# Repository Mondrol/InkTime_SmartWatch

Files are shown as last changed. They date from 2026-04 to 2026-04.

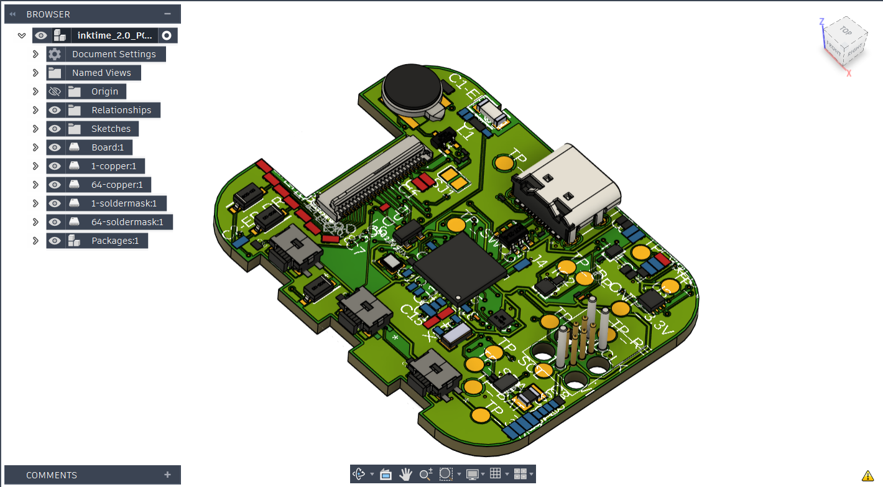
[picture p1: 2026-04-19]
Images/Screenshot 2026-04-19 184838.png

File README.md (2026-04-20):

# INK TIME SMARTWATCH

Un smartwatch bazat pe arhitectura **nRF52840**, echipat cu un ecran **e-Paper** pentru consum ultra-redus de energie și un sistem de alertă haptică.

---

## Cuprins

1. [Diagrama Bloc](#diagrama-bloc)
2. [Descrierea Funcționalității Hardware](#descrierea-funcționalității-hardware)
3. [Bill of Materials (BOM)](#bill-of-materials-bom)
4. [Configurația Pinilor nRF52840](#configurația-pinilor-nrf52840)

---

## Diagrama Bloc

```
┌─────────────────────────────────────────────────────────────┐
│                        POWER SUPPLY                         │
│                                                             │
│  Li-Po Battery (3.7V)                                       │
│       │                                                     │
│       ▼                                                     │
│  BQ25180 (Charger IC)  ◄──── USB Type-C                     │
│       │                                                     │
│       ▼                                                     │
│  RT6160A (Buck-Boost)  ──► 3.3V stable output              │
│       │                                                     │
│  MAX17048 (Fuel Gauge) ──► I2C ──► nRF52840                 │
└─────────────────────────────────────────────────────────────┘

┌─────────────────────────────────────────────────────────────┐
│                     PROCESSING UNIT                         │
│                                                             │
│              nRF52840 (ARM Cortex-M4F)                      │
│         ┌──────────────┴──────────────┐                     │
│         │                            │                      │
│       SPI bus                     I2C bus                   │
│         │                            │                      │
│   e-Paper Display              ┌─────┴──────┐               │
│   (1.54")                      │            │               │
│                            BMA423      DRV2605L              │
│                          (Accel.)    (Haptic Driver)         │
└─────────────────────────────────────────────────────────────┘
```

---

## Descrierea Funcționalității Hardware

Sistemul este construit în jurul SoC-ului **nRF52840**, optimizat pentru un consum ultra-scăzut de energie și securitate hardware.

### Microcontroller — nRF52840

Procesor ARM Cortex-M4F cu unitate de criptare hardware CryptoCell-310. Gestionează stack-ul **Bluetooth Low Energy (BLE)** și coordonează toate perifericele. Rulează la 64 MHz, dar stă majoritatea timpului în modul **System ON Sleep** (~3 µA).

### Sistemul de Alimentare (Power Tree)

| Componentă | Rol |
|---|---|
| **BQ25180** | IC de încărcare cu Power Path — permite încărcarea bateriei LiPo și alimentarea simultană a sistemului via USB Type-C |
| **MAX17048** | Fuel Gauge — măsoară precis starea de încărcare (SoC) și tensiunea bateriei, comunicând prin I2C |
| **RT6160A** | Regulator Buck-Boost — asigură o tensiune stabilă de 3.3V indiferent de nivelul de descărcare al bateriei |

### Afișaj e-Paper (1.54")

Display de tip *Electronic Ink* care consumă curent **doar la refresh**. Include un circuit de protecție cu un PFET (DMG2305UX) pentru a opri complet alimentarea ecranului în standby, eliminând scurgerile de curent. Comunică cu MCU prin **SPI** (interfață de mare viteză).

### Senzor de Mișcare — BMA423

Accelerometru triaxial de mică putere (12-bit, 3 axe). Utilizat pentru:
- **Pedometru** (numărarea pașilor)
- **Detectarea gesturilor** — ex: *tilt-to-wake* (ridicarea mâinii aprinde ecranul)

### Driver Haptic — DRV2605L

Controlează motorul de vibrații (ERM/LRA) folosind librării de efecte pre-programate pentru feedback tactil. Comunică prin **I2C**.

### Cristale de Referință

**Cristal 32 MHz (X1)** — esențial pentru funcționarea blocului radio (Bluetooth). Oferă referința de înaltă frecvență necesară stabilității semnalului RF și procesării rapide a datelor.

**Cristal 32.768 kHz (X2)** — componentă critică pentru optimizarea consumului. Permite funcționarea ceasului de timp real (RTC) în modurile de **Deep Sleep**, menținând precizia timpului cu un consum infim de energie, fără a fi nevoie de oscilatorul intern RC (mai puțin precis și mai consumator).

### Antena 2.4 GHz

Antenă de tip **SMD ceramic** (Johanson 2450AT18B100E) pentru frecvența de 2.4 GHz (BLE). A fost respectată o zonă de *keep-out* (fără cupru) pe toate straturile sub antenă pentru a preveni atenuarea semnalului.

### Interfețe de Comunicație

| Interfață | Periferice conectate |
|---|---|
| **I2C** | BMA423, DRV2605L, BQ25180, MAX17048 |
| **SPI** | Display e-Paper (interfață de mare viteză) |
| **GPIO cu întreruperi** | Butoane UP / ENTER / DOWN |
| **SWD** | Programare și debugging via Tag-Connect (J2) |

### Consumul de Energie

Bateria de **250 mAh** susține o autonomie estimată de **30–45 zile**, datorită:
- Ecranului e-Paper care nu consumă energie între actualizări
- Senzorilor configurați pe modul de consum minim cu întreruperi
- nRF52840 în System ON Sleep (~3 µA) marea majoritate a timpului

---

## Bill of Materials (BOM)

| Componentă | Descriere | Qty | Ref. Designator | Producător |
|---|---|:---:|---|---|
| **nRF52840** | MCU ARM Cortex-M4F + BLE 5.0 | 1 | U1 | Nordic Semiconductor |
| **BQ25180YBGR** | IC Încărcare Baterie Li-Po/Li-Ion | 1 | IC1 | Texas Instruments |
| **MAX17048G+T10** | Fuel Gauge 1-Cell cu ModelGauge | 1 | U2 | Analog Devices (Maxim) |
| **RT6160AWSC** | Regulator Buck-Boost DC-DC I2C | 1 | IC9 | Richtek |
| **DRV2605YZFR** | Driver Haptic ERM/LRA | 1 | IC2 | Texas Instruments |
| **BMA423** | Accelerometru Triaxial Low-g 12-bit | 1 | IC3 | Bosch Sensortec |
| **2450AT18B100E** | Antenă SMD 2.45 GHz (BLE) | 1 | ANT1 | Johanson Technology |
| **KH-TYPE-C-16P** | Conector USB Type-C 16 pini | 1 | J4 | Kinghelm |
| **503480-2400** | Conector FPC 24 pini, pitch 0.5mm (Display) | 1 | J1 | Molex |
| **TC2030-IDC** | Conector programare Tag-Connect 6 pini | 1 | J2 | Tag-Connect |
| **USBLC6-2SC6Y** | Diodă TVS Protecție ESD (USB) | 1 | D3 | STMicroelectronics |
| **MBR0530** | Diodă Schottky 30V / 0.5A | 3 | D2, D4, D5 | ON Semiconductor |
| **DMG2305UX-7** | MOSFET P-Channel 20V / 4.2A (e-Paper power switch) | 1 | Q1 | Diodes Inc. |
| **SI1308EDL-T1-GE3** | MOSFET N-Channel 30V / 1.5A | 1 | Q3 | Vishay Siliconix |
| **EVP-AKE31A** | Butoane Tactile SMD (Navigare) | 3 | SW_UP, SW_DN, SW_ENT | Panasonic |
| **744043680** | Inductor / Bobină 68 µH | 1 | L5 | Würth Elektronik |
| **FTC252012SR47MBCA** | Inductor SMD 0.47 µH | 1 | L7 | TDK |
| **Cristal 32 MHz** | Referință RF pentru bloc radio BLE | 1 | X1 | — |
| **Cristal 32.768 kHz** | Referință RTC pentru Deep Sleep | 1 | X2 | — |
| **Condensatori / Rezistențe** | Pasive SMD (0201, 0402) | ~60 | C*, R* | — |
| **Test Pads** | Puncte de test (3.3V, GND, SWD, I2C etc.) | 14 | TP_* | — |

---

## Configurația Pinilor nRF52840

### Interfața Ecranului e-Paper (SPI)

| Semnal | Pin nRF52 | Direcție | Descriere |
|---|---|---|---|
| EPD_SCK | P0.28 | Output | Clock SPI pentru refresh ecran |
| EPD_MOSI | P0.29 | Output | Date imagine (frame buffer) |
| EPD_CS | P0.30 | Output | Chip Select — activează comunicația cu display-ul |
| EPD_DC | P0.31 | Output | Data/Command — diferențiază comenzile de datele de imagine |
| EPD_BUSY | P0.04 | Input | Semnal activ cât timp ecranul procesează un refresh |
| EPD_PWR | P0.13 | Output | Enable alimentare ecran — dezactivat complet în standby |

### Magistrala Senzorilor (I2C)

Toți senzorii (BMA423, MAX17048, DRV2605L, BQ25180) împart aceeași magistrală I2C.

| Semnal | Pin nRF52 | Descriere |
|---|---|---|
| I2C_SDA | P0.26 | Linie de date (partajată între toți senzorii) |
| I2C_SCL | P0.27 | Linie de clock |

### Butoane de Navigare

Pini configurați cu pull-up intern și capabili de **wake-up din Deep Sleep** prin întrerupere hardware.

| Buton | Pin nRF52 | Funcție |
|---|---|---|
| UP | P1.00 | Navigare meniu — sus |
| DOWN | P1.01 | Navigare meniu — jos |
| ENTER | P1.02 | Selecție / Confirmare |

### Alte Conexiuni Importante

| Semnal | Pin nRF52 | Descriere |
|---|---|---|
| SHAKER_EN | P0.02 | PWM / Enable pentru driver haptic DRV2605 |
| GAUGE_INT | P1.15 | Întrerupere de la MAX17048 la nivel critic de baterie |
| LED_1 | P0.13 | LED de stare pentru notificări vizuale |
| LED_2 | P0.14 | LED de stare secundar |
| SWDIO | — | Programare și debug via Tag-Connect J2 |
| SWDCLK | — | Clock SWD pentru J-Link |

---

## Imagini PCB

| PCB 3D View | Exploded View | Final View |
|---|---|---|
| `./Images/PCB_3D.png` | `./Images/exploded_view.png` | `./Images/final_view.png` |

---

*INK TIME SMARTWATCH — Hardware Design Documentation*

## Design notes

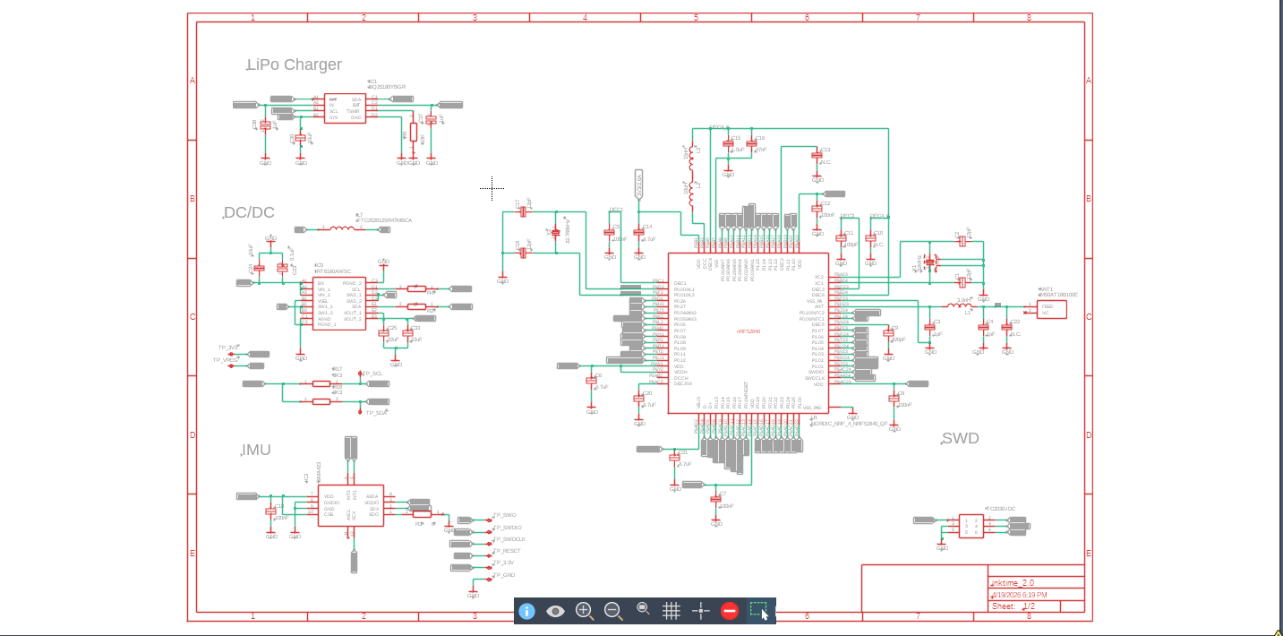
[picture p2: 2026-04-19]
Images/Screenshot 2026-04-19 184958.png

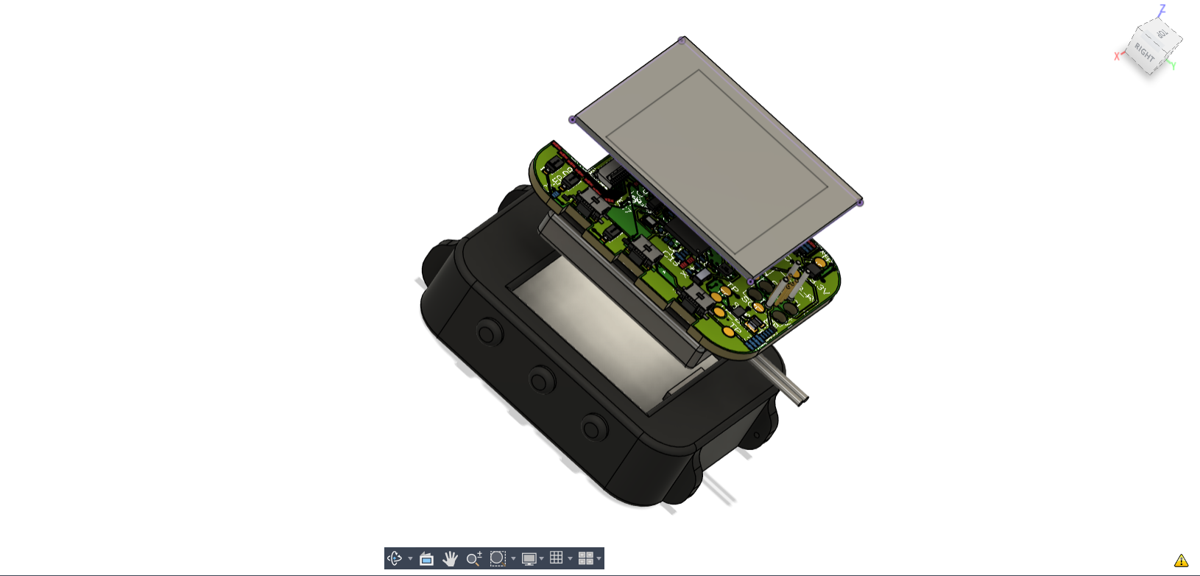
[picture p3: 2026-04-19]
Images/Screenshot 2026-04-19 185646.png

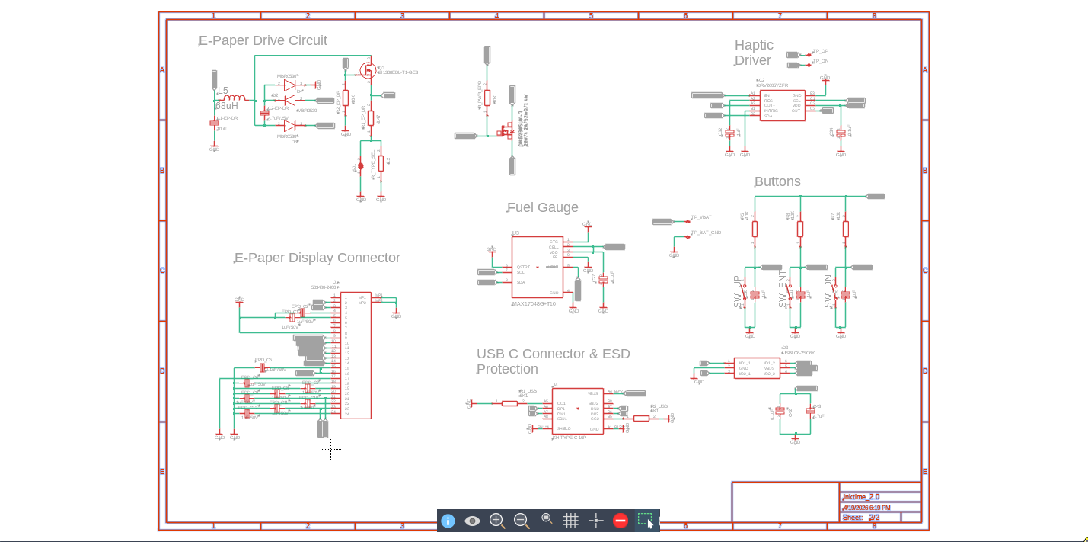
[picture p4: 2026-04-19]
Images/Screenshot 2026-04-19 184948.png

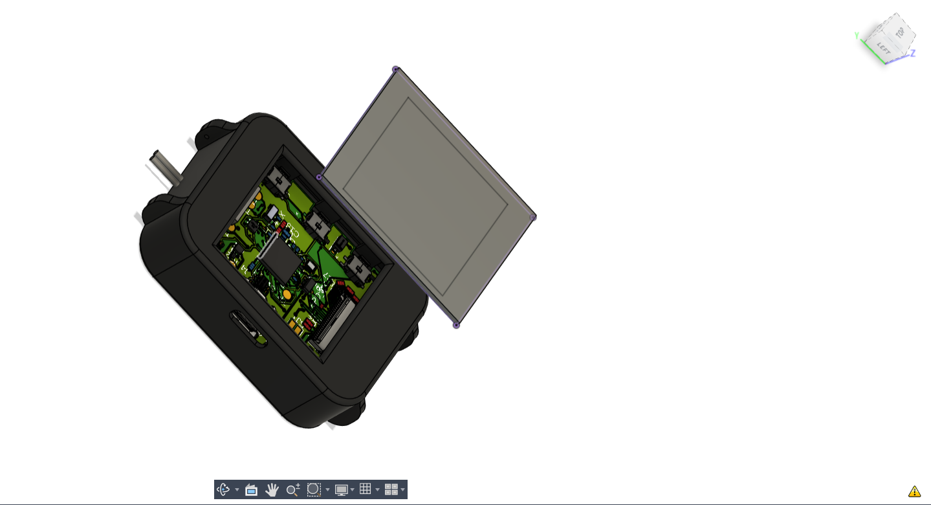
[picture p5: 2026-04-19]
Images/Screenshot 2026-04-19 185936.png

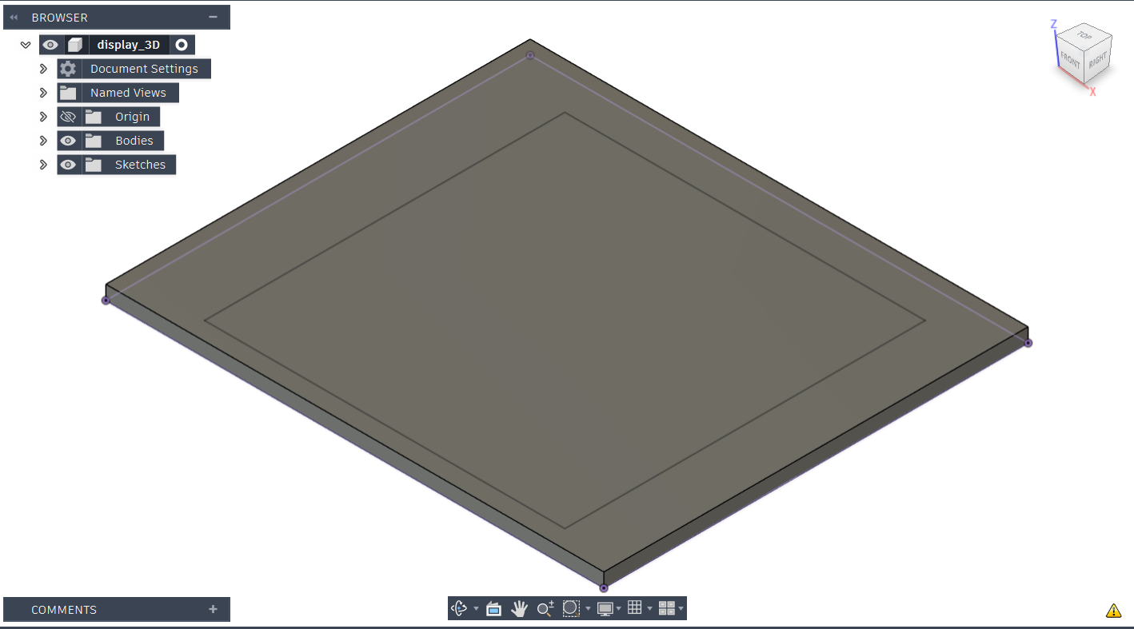
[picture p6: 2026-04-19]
Images/Screenshot 2026-04-19 184855.png

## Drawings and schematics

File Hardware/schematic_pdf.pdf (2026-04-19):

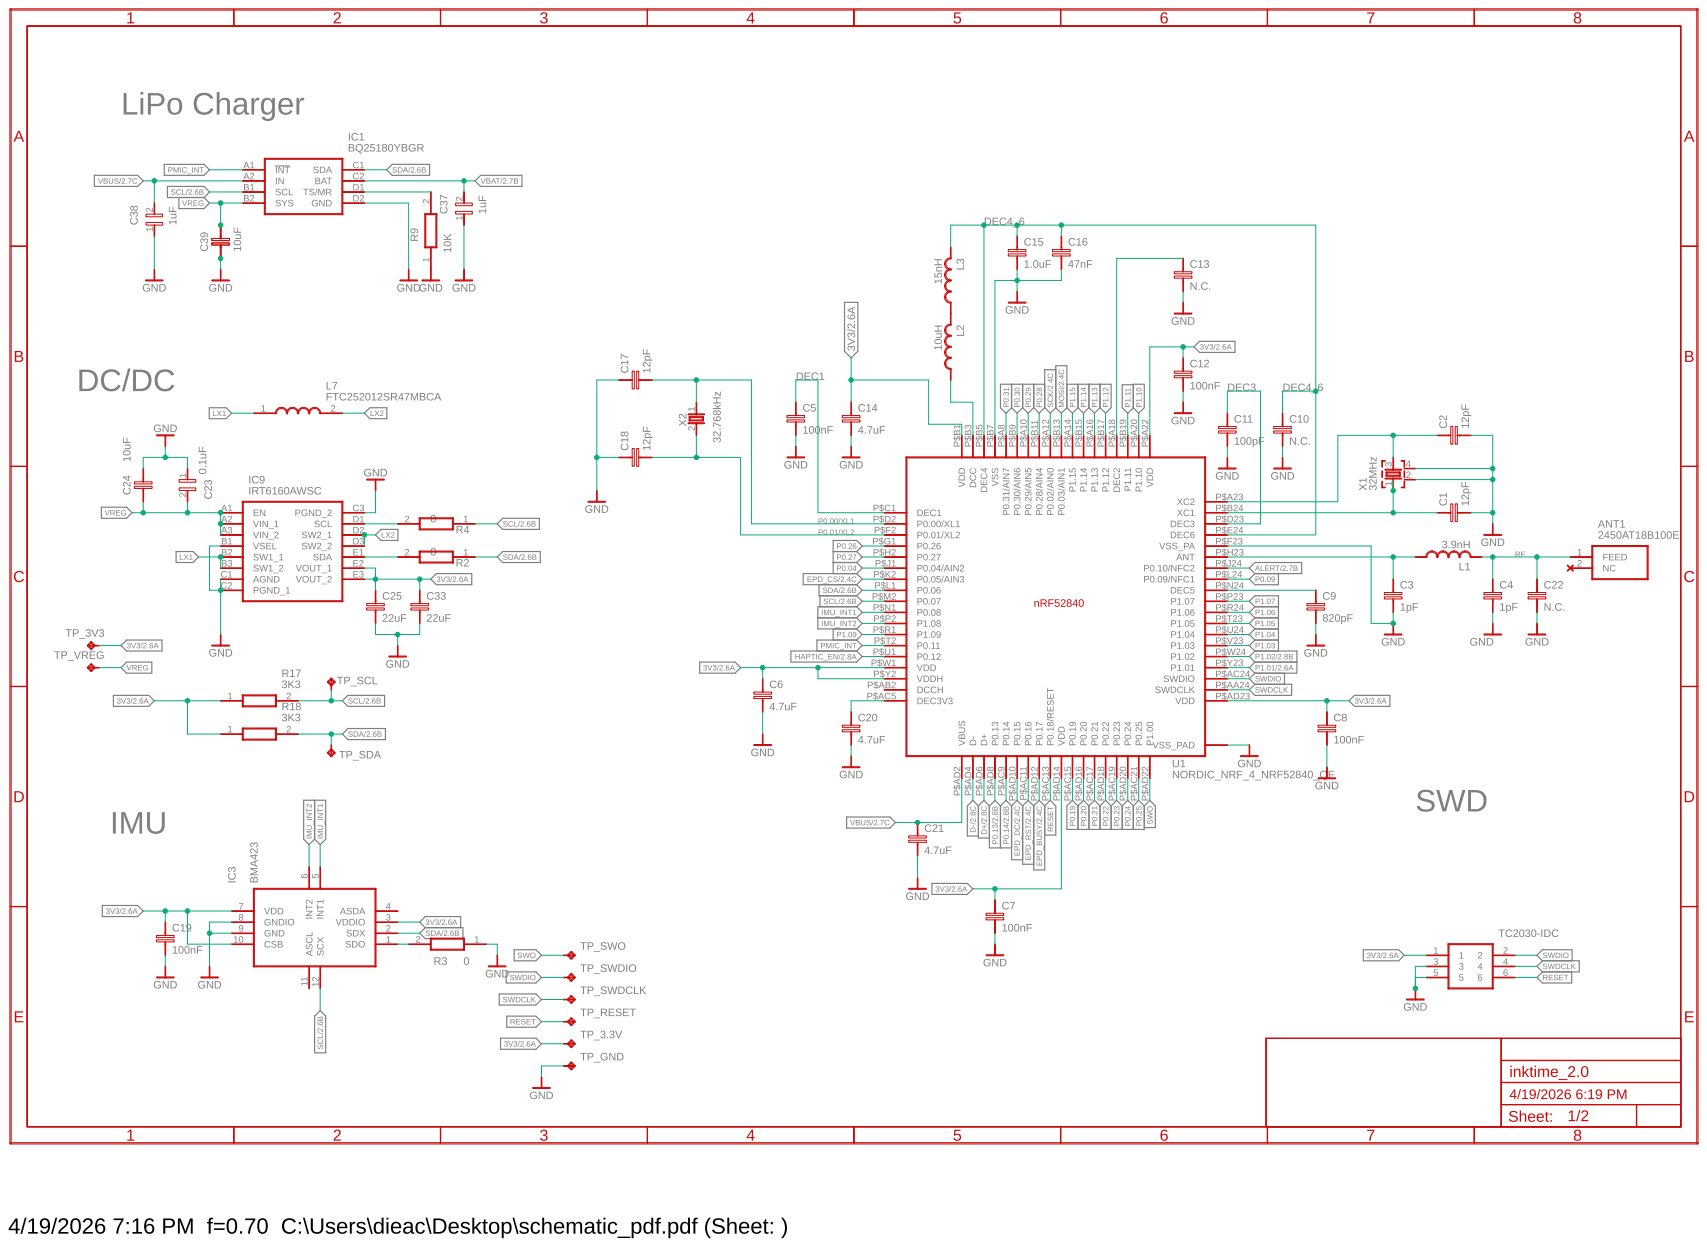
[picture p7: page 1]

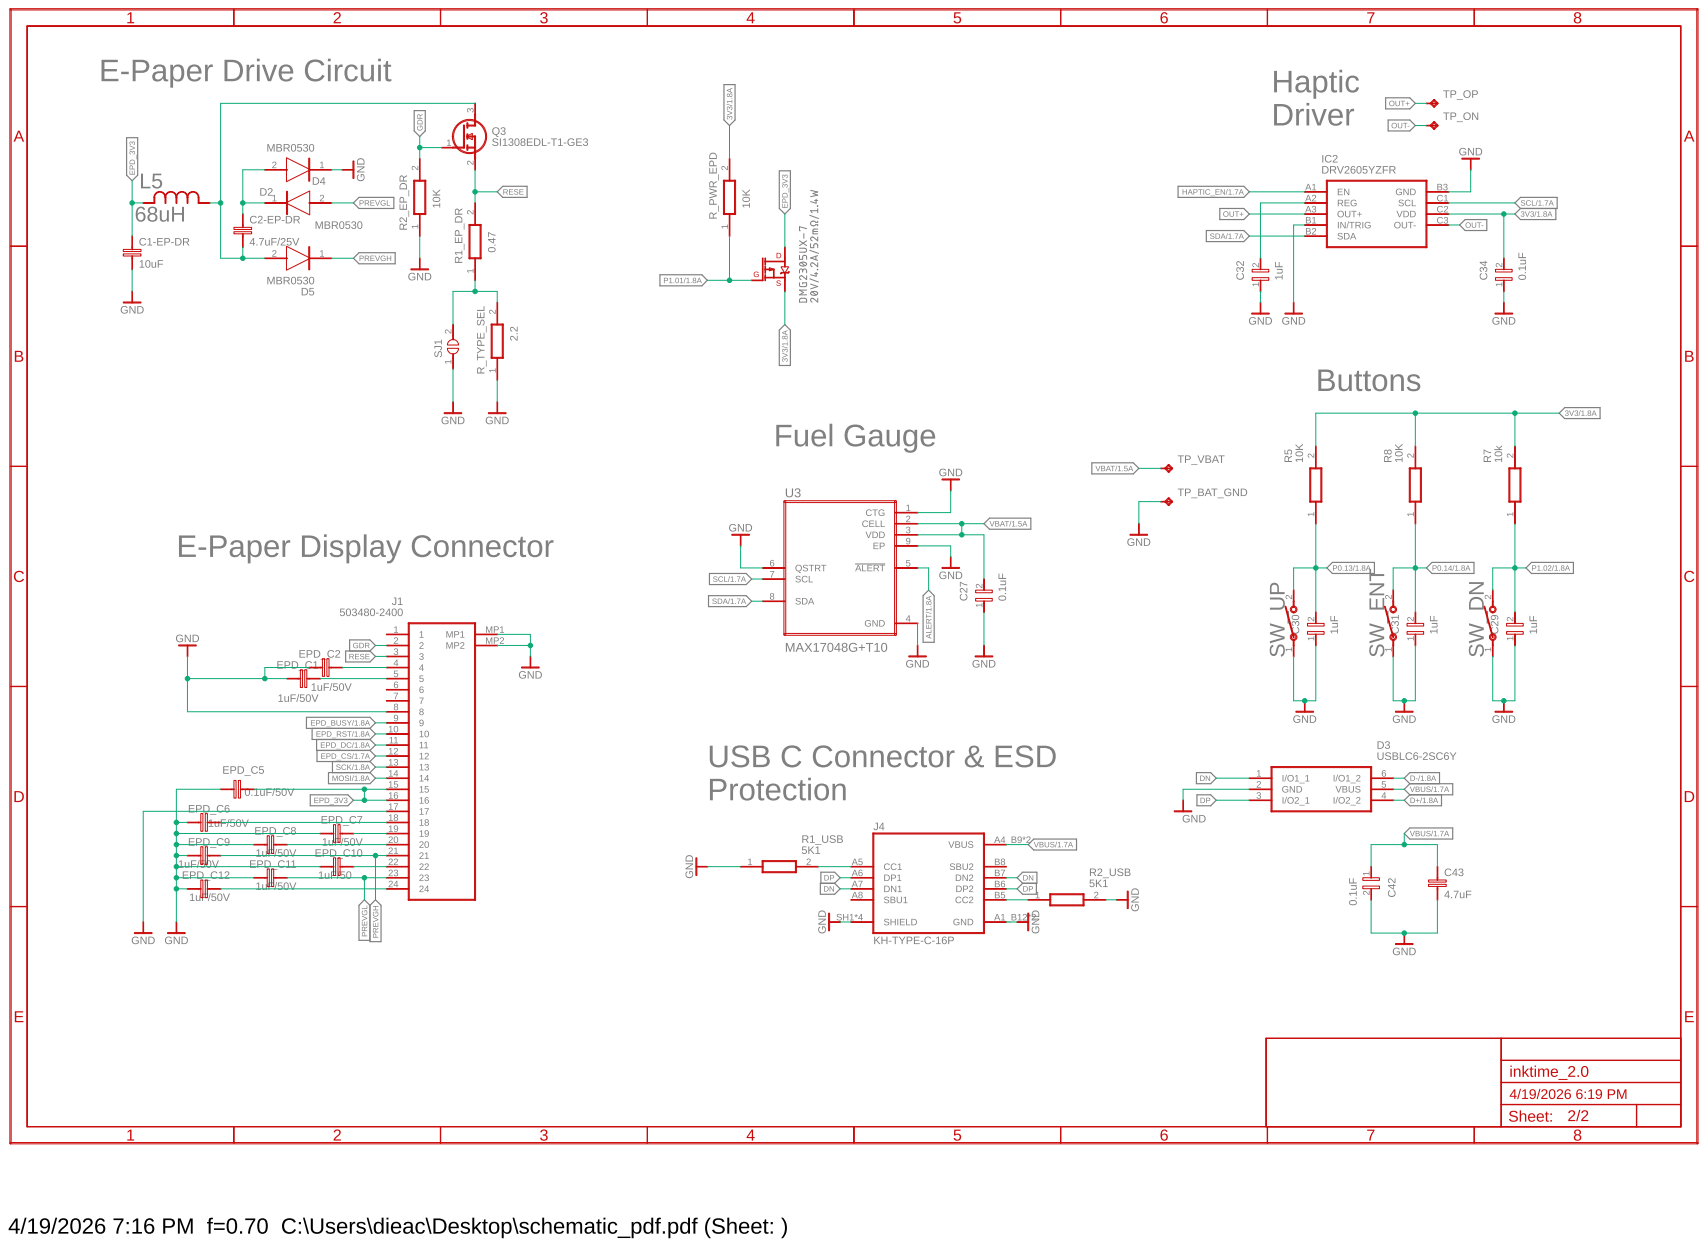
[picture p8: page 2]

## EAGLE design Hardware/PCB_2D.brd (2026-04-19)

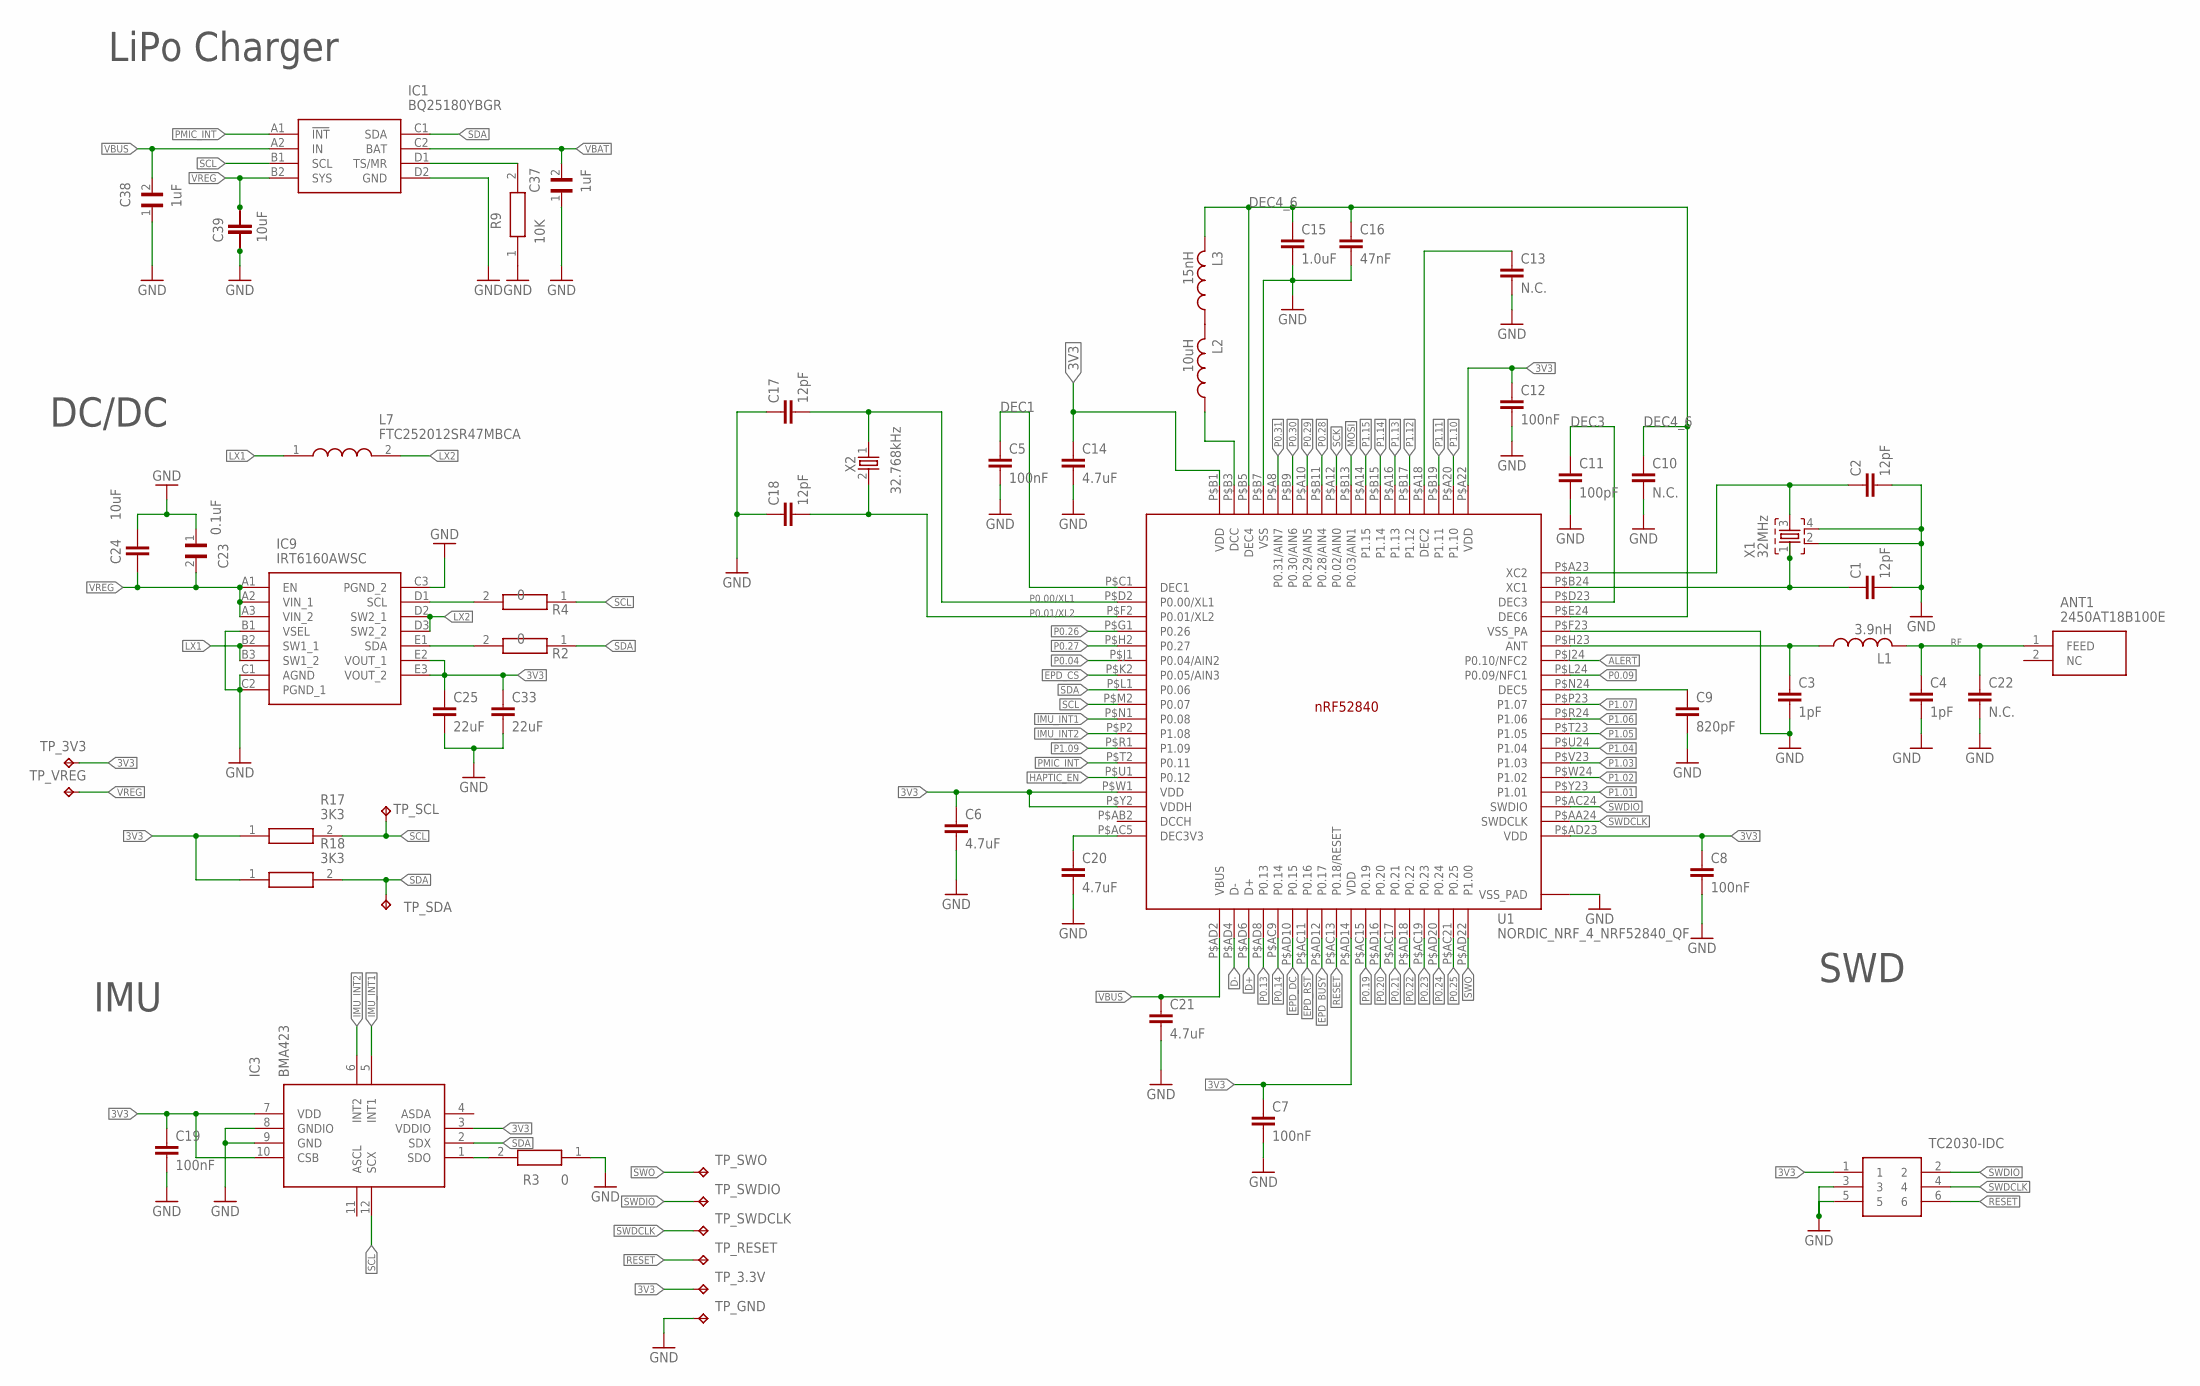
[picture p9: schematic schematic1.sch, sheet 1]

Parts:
ANT1: 2450AT18B100E; 2450AT18B100E_ANTC3216X140N
C1, C2, C17, C18: 12pF; NORDIC_NRF_3_RESC0201_L
C3, C4: 1pF; NORDIC_NRF_3_RESC0201_L
C5, C7, C8, C12, C19: 100nF; NORDIC_NRF_3_RESC0201_L
C6, C14, C20, C21: 4.7uF; NORDIC_NRF_3_RESC0402_L
C9: 820pF; NORDIC_NRF_3_RESC0201_L
C10, C13, C22: N.C.; NORDIC_NRF_3_RESC0201_L
C11: 100pF; NORDIC_NRF_3_RESC0201_L
C15: 1.0uF; NORDIC_NRF_3_RESC0402_L
C16: 47nF; NORDIC_NRF_3_RESC0201_L
C23: 0.1uF; GRM011R60J152KE01L_2_CAPC0201X13N
C24, C39: 10uF; NORDIC_NRF_3_RESC0402_L
C25, C33: 22uF; NORDIC_NRF_3_RESC0402_L
C37, C38: 1uF; GRM011R60J152KE01L_2_CAPC0201X13N
IC1: BQ25180YBGR; BQ25180YBGR_BGA8C40P2X4_100X155X50
IC3: BMA423; BMA423_BMA423
IC9: IRT6160AWSC; RT6160AWSC_BGA15C40P3X5_140X230X60
J2: TC2030-IDC; TC2030-IDC_TC2030IDC
L1: 3.9nH; NORDIC_NRF_2_RESC0402_L
L2: 10uH; NORDIC_NRF_2_RESC0402_L
L3: 15nH; NORDIC_NRF_2_RESC0402_L
L7: FTC252012SR47MBCA; MLP2016SR47MT0S1_INDC2016X100N
R2, R4: 0; ERA-1AEB3401C_0201
R3: 0; CPF0201D7K68C1_0201
R9: 10K; ERA-1AEB3401C_0201
R17, R18: 3K3; CPF0201D7K68C1_0201
TP_3.3V, TP_3V3: HECTOR_WATCH_1_TPTP20R; HECTOR_WATCH_1_TP20R
TP_GND: HECTOR_WATCH_1_TPTP20R; HECTOR_WATCH_1_TP20R
TP_RESET: HECTOR_WATCH_1_TPTP20R; HECTOR_WATCH_1_TP20R
TP_SCL: HECTOR_WATCH_1_TPTP20R; HECTOR_WATCH_1_TP20R
TP_SDA: HECTOR_WATCH_1_TPTP20R; HECTOR_WATCH_1_TP20R
TP_SWDCLK: HECTOR_WATCH_1_TPTP20R; HECTOR_WATCH_1_TP20R
TP_SWDIO: HECTOR_WATCH_1_TPTP20R; HECTOR_WATCH_1_TP20R
TP_SWO: HECTOR_WATCH_1_TPTP20R; HECTOR_WATCH_1_TP20R
TP_VREG: HECTOR_WATCH_1_TPTP20R; HECTOR_WATCH_1_TP20R
U1: NORDIC_NRF_4_NRF52840_QF; NORDIC_NRF_4_AQFN50P700X700X85_HS-74N
U$3: NORDIC_NRF_3_CAPACITOR_0402_L; NORDIC_NRF_3_RESC0402_L
X1: 32MHz; NORDIC_NRF_BT-XTAL_2016_N
X2: 32.768kHz; NORDIC_NRF_1_XTAL_3215_N

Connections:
3V3: C6.1, C7.1, C8.1, C12.1, C14.1, C19.1, C25.1, C33.1, IC3.3 (VDDIO), IC3.7 (VDD), IC3.10 (CSB), IC9.E2 (VOUT_1), IC9.E3 (VOUT_2), J2.1, R17.1, R18.1, TP_3.3V.TP, TP_3V3.TP, U1.P$A22 (VDD), U1.P$AD14 (VDD), U1.P$AD23 (VDD), U1.P$B1 (VDD), U1.P$W1 (VDD), U1.P$Y2 (VDDH); also elsewhere on the board
ALERT: U1.P$J24 (P0.10/NFC2); also elsewhere on the board
D+: U1.P$AD6 (D+); also elsewhere on the board
D-: U1.P$AD4 (D-); also elsewhere on the board
DEC1: C5.1, U1.P$C1 (DEC1)
DEC3: C11.1, U1.P$D23 (DEC3)
DEC4_6: C10.1, C15.1, C16.1, L3.2, U1.P$B5 (DEC4), U1.P$E24 (DEC6)
EPD_BUSY: U1.P$AD12 (P0.17); also elsewhere on the board
EPD_CS: U1.P$K2 (P0.05/AIN3); also elsewhere on the board
EPD_DC: U1.P$AD10 (P0.15); also elsewhere on the board
EPD_RST: U1.P$AC11 (P0.16); also elsewhere on the board
GND: C1.2, C2.2, C3.2, C4.2, C5.2, C6.2, C7.2, C8.2, C9.2, C10.2, C11.2, C12.2, C13.2, C14.2, C15.2, C16.2, C17.1, C18.1, C19.2, C20.2, C21.2, C22.2, C23.1, C24.1, C25.2, C33.2, C37.1, C38.1, C39.2, IC1.D2 (GND), IC3.8 (GNDIO), IC3.9 (GND), IC9.B1 (VSEL), IC9.C1 (AGND), IC9.C2 (PGND_1), IC9.C3 (PGND_2), J2.3, J2.5, R3.1, R9.1, TP_GND.TP, U1.P$74 (VSS_PAD), U1.P$75 (VSS_PAD), U1.P$76 (VSS_PAD), U1.P$77 (VSS_PAD), U1.P$78 (VSS_PAD), U1.P$79 (VSS_PAD), U1.P$80 (VSS_PAD), U1.P$81 (VSS_PAD), U1.P$82 (VSS_PAD), U1.P$83 (VSS_PAD), U1.P$84 (VSS_PAD), U1.P$85 (VSS_PAD), U1.P$86 (VSS_PAD), U1.P$87 (VSS_PAD), U1.P$88 (VSS_PAD), U1.P$89 (VSS_PAD), U1.P$90 (VSS_PAD), U1.P$B7 (VSS), U1.P$F23 (VSS_PA), U$3.2, X1.2, X1.4; also elsewhere on the board
HAPTIC_EN: U1.P$U1 (P0.12); also elsewhere on the board
IMU_INT1: IC3.5 (INT1), U1.P$N1 (P0.08)
IMU_INT2: IC3.6 (INT2), U1.P$P2 (P1.08)
LX1: IC9.B2 (SW1_1), IC9.B3 (SW1_2), L7.1
LX2: IC9.D2 (SW2_1), IC9.D3 (SW2_2), L7.2
MOSI: U1.P$B13 (P0.03/AIN1); also elsewhere on the board
unnamed: C2.1, U1.P$A23 (XC2), X1.3
unnamed: C1.1, U1.P$B24 (XC1), X1.1
unnamed: L2.2, L3.1
unnamed: L2.1, U1.P$B3 (DCC)
unnamed: IC3.1 (SDO), R3.2
unnamed: C3.1, L1.1, U1.P$H23 (ANT)
unnamed: C13.1, U1.P$A18 (DEC2)
unnamed: C9.1, U1.P$N24 (DEC5)
unnamed: C20.1, U1.P$AC5 (DEC3V3)
unnamed: IC9.D1 (SCL), R4.2
unnamed: IC1.D1 (TS/MR), R9.2
unnamed: IC9.E1 (SDA), R2.2
P0.00/XL1: C17.2, U1.P$D2 (P0.00/XL1), X2.1
P0.01/XL2: C18.2, U1.P$F2 (P0.01/XL2), X2.2
P0.04: U1.P$J1 (P0.04/AIN2)
P0.09: U1.P$L24 (P0.09/NFC1)
P0.13: U1.P$AD8 (P0.13); also elsewhere on the board
P0.14: U1.P$AC9 (P0.14); also elsewhere on the board
P0.19: U1.P$AC15 (P0.19)
P0.20: U1.P$AD16 (P0.20)
P0.21: U1.P$AC17 (P0.21)
P0.22: U1.P$AD18 (P0.22)
P0.23: U1.P$AC19 (P0.23)
P0.24: U1.P$AD20 (P0.24)
P0.25: U1.P$AC21 (P0.25)
P0.26: U1.P$G1 (P0.26)
P0.27: U1.P$H2 (P0.27)
P0.28: U1.P$B11 (P0.28/AIN4)
P0.29: U1.P$A10 (P0.29/AIN5)
P0.30: U1.P$B9 (P0.30/AIN6)
P0.31: U1.P$A8 (P0.31/AIN7)
P1.01: U1.P$Y23 (P1.01); also elsewhere on the board
P1.02: U1.P$W24 (P1.02); also elsewhere on the board
P1.03: U1.P$V23 (P1.03)
P1.04: U1.P$U24 (P1.04)
P1.05: U1.P$T23 (P1.05)
P1.06: U1.P$R24 (P1.06)
P1.07: U1.P$P23 (P1.07)
P1.09: U1.P$R1 (P1.09)
P1.10: U1.P$A20 (P1.10)
P1.11: U1.P$B19 (P1.11)
P1.12: U1.P$B17 (P1.12)
P1.13: U1.P$A16 (P1.13)
P1.14: U1.P$B15 (P1.14)
P1.15: U1.P$A14 (P1.15)
PMIC_INT: IC1.A1 (!INT), U1.P$T2 (P0.11)
RESET: J2.6, TP_RESET.TP, U1.P$AC13 (P0.18/RESET)
RF: ANT1.1 (FEED), C4.1, C22.1, L1.2
SCK: U1.P$A12 (P0.02/AIN0); also elsewhere on the board
SCL: IC1.B1 (SCL), IC3.12 (SCX), R4.1, R17.2, TP_SCL.TP, U1.P$M2 (P0.07); also elsewhere on the board
SDA: IC1.C1 (SDA), IC3.2 (SDX), R2.1, R18.2, TP_SDA.TP, U1.P$L1 (P0.06); also elsewhere on the board
SWDCLK: J2.4, TP_SWDCLK.TP, U1.P$AA24 (SWDCLK)
SWDIO: J2.2, TP_SWDIO.TP, U1.P$AC24 (SWDIO)
SWO: TP_SWO.TP, U1.P$AD22 (P1.00)
VBAT: C37.2, IC1.C2 (BAT); also elsewhere on the board
VBUS: C21.1, C38.2, IC1.A2 (IN), U1.P$AD2 (VBUS); also elsewhere on the board
VREG: C23.2, C24.2, C39.1, IC1.B2 (SYS), IC9.A1 (EN), IC9.A2 (VIN_1), IC9.A3 (VIN_2), TP_VREG.TP, U$3.1

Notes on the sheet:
LiPo Charger
DC/DC
IMU
SWD

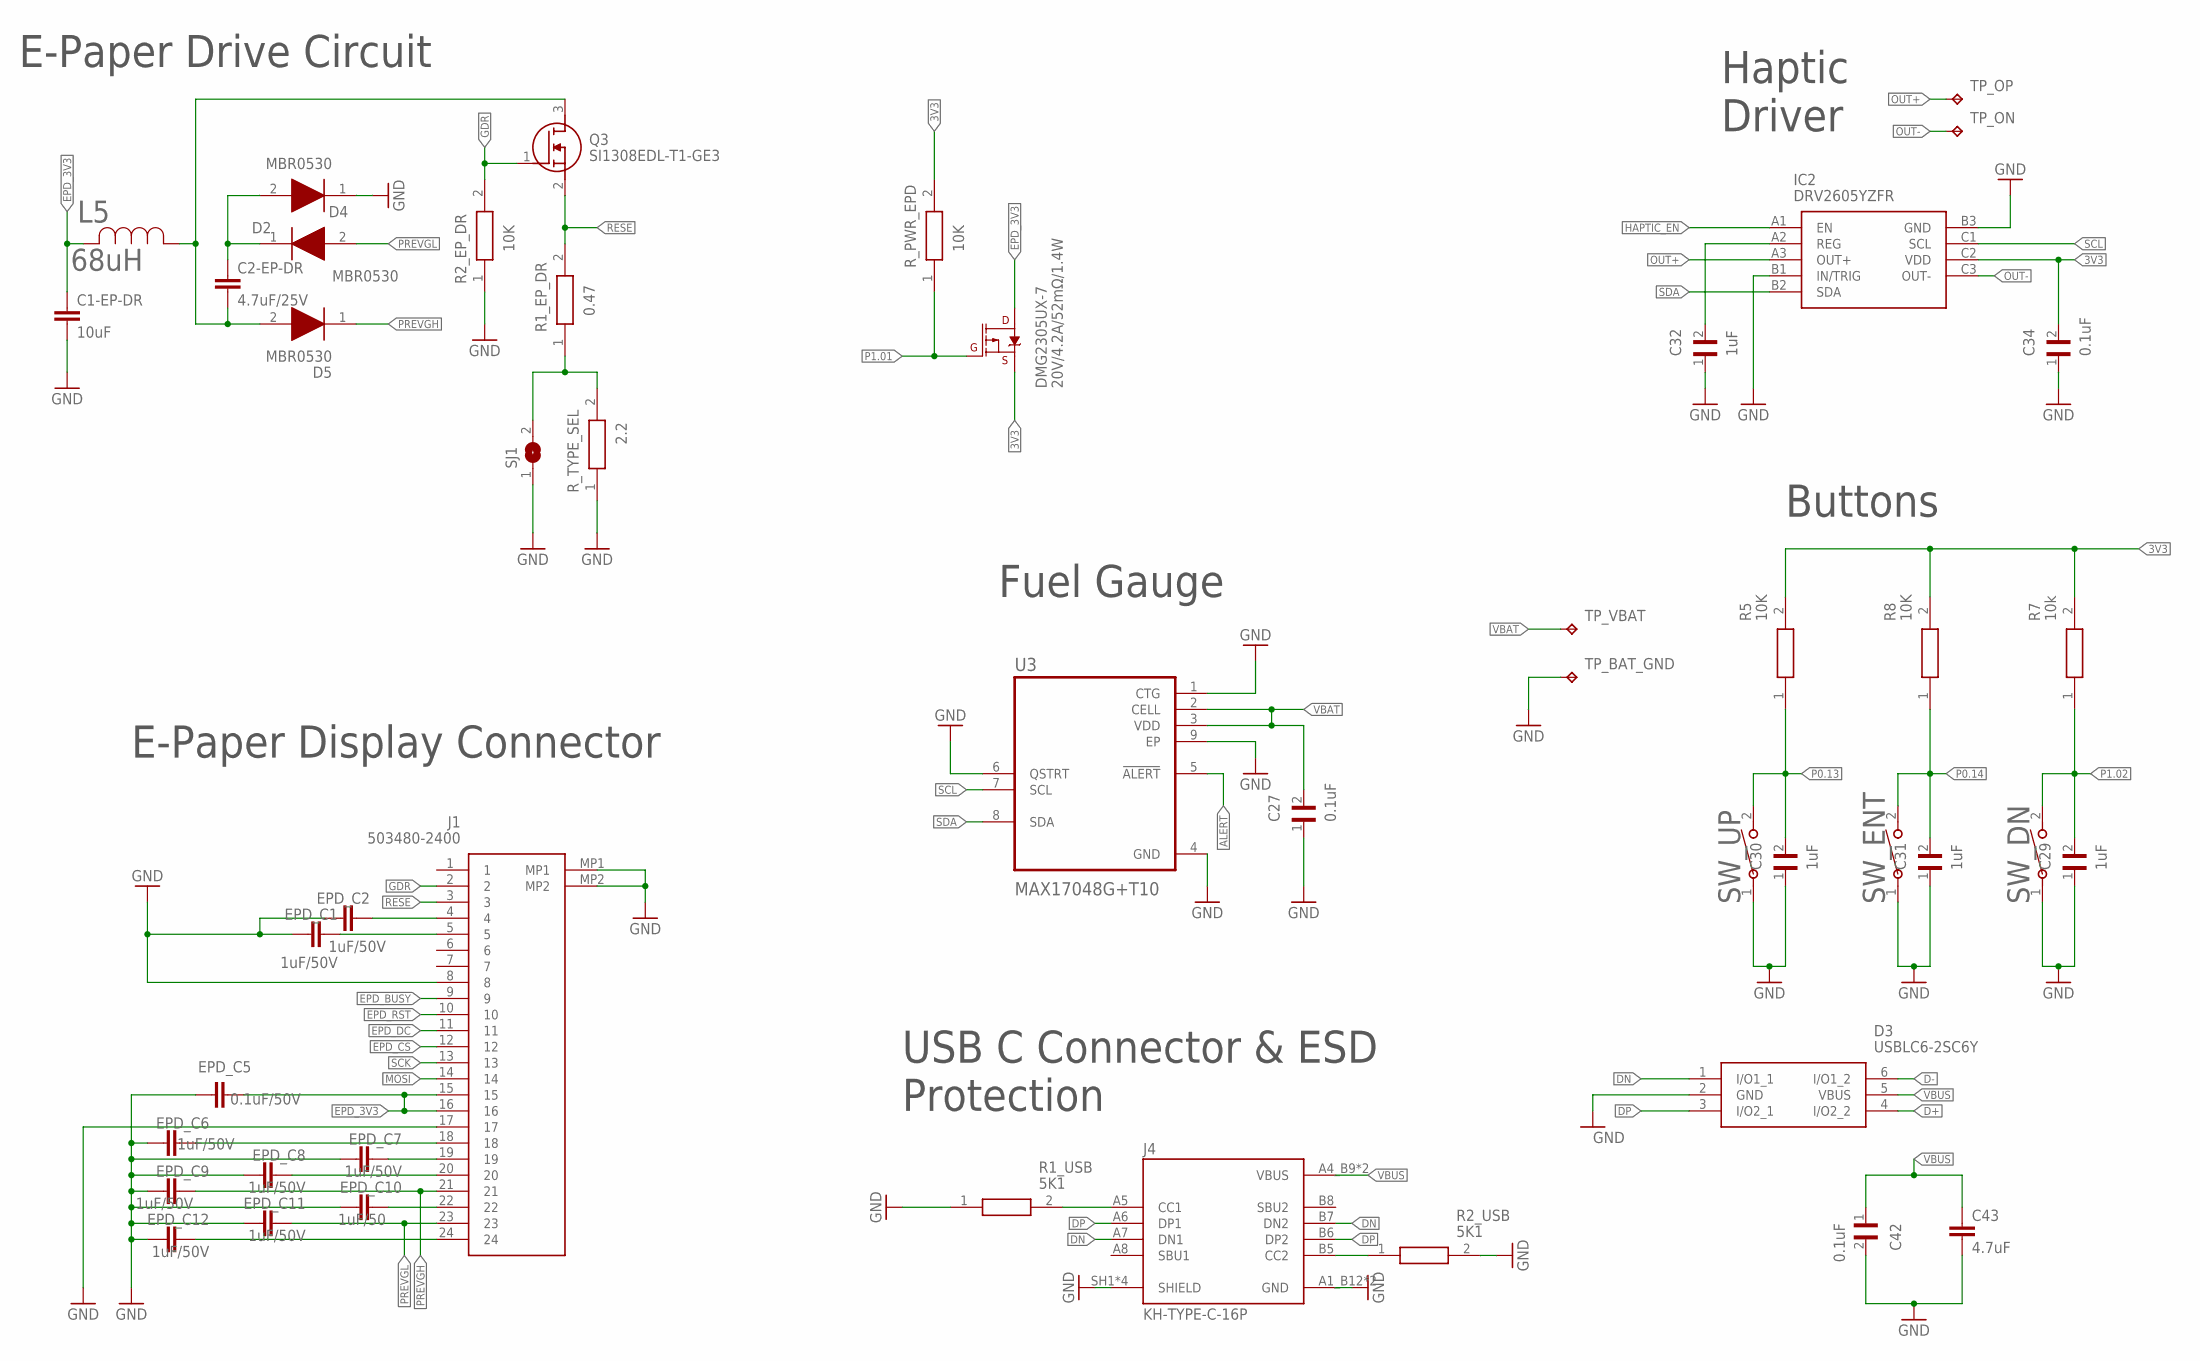
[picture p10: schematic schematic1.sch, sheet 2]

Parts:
C1-EP-DR: 10uF; NORDIC_NRF_3_RESC0402_L
C2-EP-DR: 4.7uF/25V; NORDIC_NRF_3_RESC0402_L
C27, C34, C42: 0.1uF; GRM011R60J152KE01L_2_CAPC0201X13N
C29, C30, C31, C32: 1uF; GRM011R60J152KE01L_2_CAPC0201X13N
C43: 4.7uF; NORDIC_NRF_3_RESC0402_L
D2, D4, D5: MBR0530; ESP32_C6_LIBRARY_5_SOD3716X135N
D3: USBLC6-2SC6Y; ESP32_C6_LIBRARY_3_SOT95P280X145-6N
DMG2305UX-7: 20V/4.2A/52mΩ/1.4W; ESP32_C6_LIBRARY_4_ESP32_C6_LIBRARY_4_ESP32_C6_LIBRARY_4_ES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
EPD_C1, EPD_C2, EPD_C6, EPD_C7, EPD_C8, EPD_C9, EPD_C11, EPD_C12: 1uF/50V; NORDIC_NRF_3_RESC0402_L
EPD_C5: 0.1uF/50V; NORDIC_NRF_3_RESC0201_L
EPD_C10: 1uF/50; NORDIC_NRF_3_RESC0402_L
IC2: DRV2605YZFR; DRV2605YZFR_BGA9C50P3X3_144X144X62
J1: 503480-2400; 503480-2400_5034802400
J4: KH-TYPE-C-16P; KH-TYPE-C-16P_KINGHELM_KH-TYPE-C-16P
L5: 68uH; ESP32_C6_LIBRARY_2_IND_4828-WE-TPC_WRE
Q3: SI1308EDL-T1-GE3; ESP32_C6_LIBRARY_6_SOT65P210X110-3N
R1_EP_DR: 0.47; ERA-1AEB3401C_0201
R1_USB, R2_USB: 5K1; ERA-1AEB3401C_0201
R2_EP_DR, R5, R8: 10K; ERA-1AEB3401C_0201
R7: 10k; ERA-1AEB3401C_0201
R_PWR_EPD: 10K; ERA-1AEB3401C_0201
R_TYPE_SEL: 2.2; ERA-1AEB3401C_0201
SJ1: ESP32_C6_LIBRARY_7_JUMPER_SJ
SW_DN: 2025-10-22_07-23-44_LIBRARY_EVP-AKE31ASW_EVP-AKE3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; 2025-10-22_07-23-44_LIBRARY_SW_EVP-AKE31A_PAN
SW_ENT: 2025-10-22_07-23-44_LIBRARY_EVP-AKE31ASW_EVP-AKE3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; 2025-10-22_07-23-44_LIBRARY_SW_EVP-AKE31A_PAN
SW_UP: 2025-10-22_07-23-44_LIBRARY_EVP-AKE31ASW_EVP-AKE3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; 2025-10-22_07-23-44_LIBRARY_SW_EVP-AKE31A_PAN
TP_BAT_GND: HECTOR_WATCH_1_TPTP20R; HECTOR_WATCH_1_TP20R
TP_ON: HECTOR_WATCH_1_TPTP20R; HECTOR_WATCH_1_TP20R
TP_OP: HECTOR_WATCH_1_TPTP20R; HECTOR_WATCH_1_TP20R
TP_VBAT: HECTOR_WATCH_1_TPTP20R; HECTOR_WATCH_1_TP20R
U3: MAX17048G+T10; ESP32_C6_LIBRARY_SON50P200X200X80-9N

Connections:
3V3: C34.2, DMG2305UX-7.2 (S), IC2.C2 (VDD), R5.2, R7.2, R8.2, R_PWR_EPD.2; also elsewhere on the board
ALERT: U3.5 (!ALERT); also elsewhere on the board
D+: D3.4 (I/O2_2); also elsewhere on the board
D-: D3.6 (I/O1_2); also elsewhere on the board
DN: D3.1 (I/O1_1), J4.A7 (DN1), J4.B7 (DN2)
DP: D3.3 (I/O2_1), J4.A6 (DP1), J4.B6 (DP2)
EPD_3V3: C1-EP-DR.1, DMG2305UX-7.3 (D), EPD_C5.1, J1.15, J1.16, L5.2
EPD_BUSY: J1.9; also elsewhere on the board
EPD_CS: J1.12; also elsewhere on the board
EPD_DC: J1.11; also elsewhere on the board
EPD_RST: J1.10; also elsewhere on the board
GDR: J1.2, Q3.1 (G), R2_EP_DR.2
GND: C1-EP-DR.2, C27.1, C29.1, C30.1, C31.1, C32.1, C34.1, C42.2, C43.2, D3.2 (GND), D4.1 (K), EPD_C1.1, EPD_C2.1, EPD_C5.2, EPD_C6.1, EPD_C7.1, EPD_C8.1, EPD_C9.1, EPD_C10.1, EPD_C11.1, EPD_C12.1, IC2.B1 (IN/TRIG), IC2.B3 (GND), J1.8, J1.17, J1.MP1, J1.MP2, J4.A1_B12 (GND), J4.A12_B1 (GND), J4.SH1 (SHIELD), J4.SH2 (SHIELD), J4.SH3 (SHIELD), J4.SH4 (SHIELD), R1_USB.1, R2_EP_DR.1, R2_USB.2, R_TYPE_SEL.1, SJ1.1, SW_DN.1, SW_ENT.1, SW_UP.1, TP_BAT_GND.TP, U3.1 (CTG), U3.4 (GND), U3.6 (QSTRT), U3.9 (EP); also elsewhere on the board
HAPTIC_EN: IC2.A1 (EN); also elsewhere on the board
MOSI: J1.14; also elsewhere on the board
unnamed: C32.2, IC2.A2 (REG)
unnamed: C2-EP-DR.2, D5.2 (A), L5.1, Q3.3 (D)
unnamed: C2-EP-DR.1, D2.1 (K), D4.2 (A)
unnamed: J4.B5 (CC2), R2_USB.1
unnamed: J4.A5 (CC1), R1_USB.2
unnamed: EPD_C2.2, J1.4
unnamed: EPD_C1.2, J1.5
unnamed: R1_EP_DR.1, R_TYPE_SEL.2, SJ1.2
unnamed: EPD_C6.2, J1.18
unnamed: EPD_C7.2, J1.19
unnamed: EPD_C8.2, J1.20
unnamed: EPD_C10.2, J1.22
unnamed: EPD_C12.2, J1.24
OUT+: IC2.A3 (OUT+), TP_OP.TP
OUT-: IC2.C3 (OUT-), TP_ON.TP
P0.13: C30.2, R5.1, SW_UP.2; also elsewhere on the board
P0.14: C31.2, R8.1, SW_ENT.2; also elsewhere on the board
P1.01: DMG2305UX-7.1 (G), R_PWR_EPD.1; also elsewhere on the board
P1.02: C29.2, R7.1, SW_DN.2; also elsewhere on the board
PREVGH: D5.1 (K), EPD_C9.2, J1.21
PREVGL: D2.2 (A), EPD_C11.2, J1.23
RESE: J1.3, Q3.2 (S), R1_EP_DR.2
SCK: J1.13; also elsewhere on the board
SCL: IC2.C1 (SCL), U3.7 (SCL); also elsewhere on the board
SDA: IC2.B2 (SDA), U3.8 (SDA); also elsewhere on the board
VBAT: C27.2, TP_VBAT.TP, U3.2 (CELL), U3.3 (VDD); also elsewhere on the board
VBUS: C42.1, C43.1, D3.5 (VBUS), J4.A4_B9 (VBUS), J4.A9_B4 (VBUS); also elsewhere on the board

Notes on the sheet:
E-Paper Drive Circuit
E-Paper Display Connector
Fuel Gauge
Haptic Driver
Buttons
USB C Connector & ESD Protection


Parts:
ANT1: 2450AT18B100E; 2450AT18B100E_ANTC3216X140N
C1, C2, C17, C18: 12pF; NORDIC_NRF_3_RESC0201_L
C3, C4: 1pF; NORDIC_NRF_3_RESC0201_L
C5, C7, C8, C12, C19: 100nF; NORDIC_NRF_3_RESC0201_L
C6, C14, C20, C21: 4.7uF; NORDIC_NRF_3_RESC0402_L
C9: 820pF; NORDIC_NRF_3_RESC0201_L
C10, C13, C22: N.C.; NORDIC_NRF_3_RESC0201_L
C11: 100pF; NORDIC_NRF_3_RESC0201_L
C15: 1.0uF; NORDIC_NRF_3_RESC0402_L
C16: 47nF; NORDIC_NRF_3_RESC0201_L
C23: 0.1uF; GRM011R60J152KE01L_2_CAPC0201X13N
C24, C39: 10uF; NORDIC_NRF_3_RESC0402_L
C25, C33: 22uF; NORDIC_NRF_3_RESC0402_L
C37, C38: 1uF; GRM011R60J152KE01L_2_CAPC0201X13N
IC1: BQ25180YBGR; BQ25180YBGR_BGA8C40P2X4_100X155X50
IC3: BMA423; BMA423_BMA423
IC9: IRT6160AWSC; RT6160AWSC_BGA15C40P3X5_140X230X60
J2: TC2030-IDC; TC2030-IDC_TC2030IDC
L1: 3.9nH; NORDIC_NRF_2_RESC0402_L
L2: 10uH; NORDIC_NRF_2_RESC0402_L
L3: 15nH; NORDIC_NRF_2_RESC0402_L
L7: FTC252012SR47MBCA; MLP2016SR47MT0S1_INDC2016X100N
R2, R4: 0; ERA-1AEB3401C_0201
R3: 0; CPF0201D7K68C1_0201
R9: 10K; ERA-1AEB3401C_0201
R17, R18: 3K3; CPF0201D7K68C1_0201
TP_3.3V, TP_3V3: HECTOR_WATCH_1_TPTP20R; HECTOR_WATCH_1_TP20R
TP_GND: HECTOR_WATCH_1_TPTP20R; HECTOR_WATCH_1_TP20R
TP_RESET: HECTOR_WATCH_1_TPTP20R; HECTOR_WATCH_1_TP20R
TP_SCL: HECTOR_WATCH_1_TPTP20R; HECTOR_WATCH_1_TP20R
TP_SDA: HECTOR_WATCH_1_TPTP20R; HECTOR_WATCH_1_TP20R
TP_SWDCLK: HECTOR_WATCH_1_TPTP20R; HECTOR_WATCH_1_TP20R
TP_SWDIO: HECTOR_WATCH_1_TPTP20R; HECTOR_WATCH_1_TP20R
TP_SWO: HECTOR_WATCH_1_TPTP20R; HECTOR_WATCH_1_TP20R
TP_VREG: HECTOR_WATCH_1_TPTP20R; HECTOR_WATCH_1_TP20R
U1: NORDIC_NRF_4_NRF52840_QF; NORDIC_NRF_4_AQFN50P700X700X85_HS-74N
U$3: NORDIC_NRF_3_CAPACITOR_0402_L; NORDIC_NRF_3_RESC0402_L
X1: 32MHz; NORDIC_NRF_BT-XTAL_2016_N
X2: 32.768kHz; NORDIC_NRF_1_XTAL_3215_N

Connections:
3V3: C6.1, C7.1, C8.1, C12.1, C14.1, C19.1, C25.1, C33.1, IC3.3 (VDDIO), IC3.7 (VDD), IC3.10 (CSB), IC9.E2 (VOUT_1), IC9.E3 (VOUT_2), J2.1, R17.1, R18.1, TP_3.3V.TP, TP_3V3.TP, U1.P$A22 (VDD), U1.P$AD14 (VDD), U1.P$AD23 (VDD), U1.P$B1 (VDD), U1.P$W1 (VDD), U1.P$Y2 (VDDH); also elsewhere on the board
ALERT: U1.P$J24 (P0.10/NFC2); also elsewhere on the board
D+: U1.P$AD6 (D+); also elsewhere on the board
D-: U1.P$AD4 (D-); also elsewhere on the board
DEC1: C5.1, U1.P$C1 (DEC1)
DEC3: C11.1, U1.P$D23 (DEC3)
DEC4_6: C10.1, C15.1, C16.1, L3.2, U1.P$B5 (DEC4), U1.P$E24 (DEC6)
EPD_BUSY: U1.P$AD12 (P0.17); also elsewhere on the board
EPD_CS: U1.P$K2 (P0.05/AIN3); also elsewhere on the board
EPD_DC: U1.P$AD10 (P0.15); also elsewhere on the board
EPD_RST: U1.P$AC11 (P0.16); also elsewhere on the board
GND: C1.2, C2.2, C3.2, C4.2, C5.2, C6.2, C7.2, C8.2, C9.2, C10.2, C11.2, C12.2, C13.2, C14.2, C15.2, C16.2, C17.1, C18.1, C19.2, C20.2, C21.2, C22.2, C23.1, C24.1, C25.2, C33.2, C37.1, C38.1, C39.2, IC1.D2 (GND), IC3.8 (GNDIO), IC3.9 (GND), IC9.B1 (VSEL), IC9.C1 (AGND), IC9.C2 (PGND_1), IC9.C3 (PGND_2), J2.3, J2.5, R3.1, R9.1, TP_GND.TP, U1.P$74 (VSS_PAD), U1.P$75 (VSS_PAD), U1.P$76 (VSS_PAD), U1.P$77 (VSS_PAD), U1.P$78 (VSS_PAD), U1.P$79 (VSS_PAD), U1.P$80 (VSS_PAD), U1.P$81 (VSS_PAD), U1.P$82 (VSS_PAD), U1.P$83 (VSS_PAD), U1.P$84 (VSS_PAD), U1.P$85 (VSS_PAD), U1.P$86 (VSS_PAD), U1.P$87 (VSS_PAD), U1.P$88 (VSS_PAD), U1.P$89 (VSS_PAD), U1.P$90 (VSS_PAD), U1.P$B7 (VSS), U1.P$F23 (VSS_PA), U$3.2, X1.2, X1.4; also elsewhere on the board
HAPTIC_EN: U1.P$U1 (P0.12); also elsewhere on the board
IMU_INT1: IC3.5 (INT1), U1.P$N1 (P0.08)
IMU_INT2: IC3.6 (INT2), U1.P$P2 (P1.08)
LX1: IC9.B2 (SW1_1), IC9.B3 (SW1_2), L7.1
LX2: IC9.D2 (SW2_1), IC9.D3 (SW2_2), L7.2
MOSI: U1.P$B13 (P0.03/AIN1); also elsewhere on the board
unnamed: C2.1, U1.P$A23 (XC2), X1.3
unnamed: C1.1, U1.P$B24 (XC1), X1.1
unnamed: L2.2, L3.1
unnamed: L2.1, U1.P$B3 (DCC)
unnamed: IC3.1 (SDO), R3.2
unnamed: C3.1, L1.1, U1.P$H23 (ANT)
unnamed: C13.1, U1.P$A18 (DEC2)
unnamed: C9.1, U1.P$N24 (DEC5)
unnamed: C20.1, U1.P$AC5 (DEC3V3)
unnamed: IC9.D1 (SCL), R4.2
unnamed: IC1.D1 (TS/MR), R9.2
unnamed: IC9.E1 (SDA), R2.2
P0.00/XL1: C17.2, U1.P$D2 (P0.00/XL1), X2.1
P0.01/XL2: C18.2, U1.P$F2 (P0.01/XL2), X2.2
P0.04: U1.P$J1 (P0.04/AIN2)
P0.09: U1.P$L24 (P0.09/NFC1)
P0.13: U1.P$AD8 (P0.13); also elsewhere on the board
P0.14: U1.P$AC9 (P0.14); also elsewhere on the board
P0.19: U1.P$AC15 (P0.19)
P0.20: U1.P$AD16 (P0.20)
P0.21: U1.P$AC17 (P0.21)
P0.22: U1.P$AD18 (P0.22)
P0.23: U1.P$AC19 (P0.23)
P0.24: U1.P$AD20 (P0.24)
P0.25: U1.P$AC21 (P0.25)
P0.26: U1.P$G1 (P0.26)
P0.27: U1.P$H2 (P0.27)
P0.28: U1.P$B11 (P0.28/AIN4)
P0.29: U1.P$A10 (P0.29/AIN5)
P0.30: U1.P$B9 (P0.30/AIN6)
P0.31: U1.P$A8 (P0.31/AIN7)
P1.01: U1.P$Y23 (P1.01); also elsewhere on the board
P1.02: U1.P$W24 (P1.02); also elsewhere on the board
P1.03: U1.P$V23 (P1.03)
P1.04: U1.P$U24 (P1.04)
P1.05: U1.P$T23 (P1.05)
P1.06: U1.P$R24 (P1.06)
P1.07: U1.P$P23 (P1.07)
P1.09: U1.P$R1 (P1.09)
P1.10: U1.P$A20 (P1.10)
P1.11: U1.P$B19 (P1.11)
P1.12: U1.P$B17 (P1.12)
P1.13: U1.P$A16 (P1.13)
P1.14: U1.P$B15 (P1.14)
P1.15: U1.P$A14 (P1.15)
PMIC_INT: IC1.A1 (!INT), U1.P$T2 (P0.11)
RESET: J2.6, TP_RESET.TP, U1.P$AC13 (P0.18/RESET)
RF: ANT1.1 (FEED), C4.1, C22.1, L1.2
SCK: U1.P$A12 (P0.02/AIN0); also elsewhere on the board
SCL: IC1.B1 (SCL), IC3.12 (SCX), R4.1, R17.2, TP_SCL.TP, U1.P$M2 (P0.07); also elsewhere on the board
SDA: IC1.C1 (SDA), IC3.2 (SDX), R2.1, R18.2, TP_SDA.TP, U1.P$L1 (P0.06); also elsewhere on the board
SWDCLK: J2.4, TP_SWDCLK.TP, U1.P$AA24 (SWDCLK)
SWDIO: J2.2, TP_SWDIO.TP, U1.P$AC24 (SWDIO)
SWO: TP_SWO.TP, U1.P$AD22 (P1.00)
VBAT: C37.2, IC1.C2 (BAT); also elsewhere on the board
VBUS: C21.1, C38.2, IC1.A2 (IN), U1.P$AD2 (VBUS); also elsewhere on the board
VREG: C23.2, C24.2, C39.1, IC1.B2 (SYS), IC9.A1 (EN), IC9.A2 (VIN_1), IC9.A3 (VIN_2), TP_VREG.TP, U$3.1

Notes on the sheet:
LiPo Charger
DC/DC
IMU
SWD

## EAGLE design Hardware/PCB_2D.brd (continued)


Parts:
C1-EP-DR: 10uF; NORDIC_NRF_3_RESC0402_L
C2-EP-DR: 4.7uF/25V; NORDIC_NRF_3_RESC0402_L
C27, C34, C42: 0.1uF; GRM011R60J152KE01L_2_CAPC0201X13N
C29, C30, C31, C32: 1uF; GRM011R60J152KE01L_2_CAPC0201X13N
C43: 4.7uF; NORDIC_NRF_3_RESC0402_L
D2, D4, D5: MBR0530; ESP32_C6_LIBRARY_5_SOD3716X135N
D3: USBLC6-2SC6Y; ESP32_C6_LIBRARY_3_SOT95P280X145-6N
DMG2305UX-7: 20V/4.2A/52mΩ/1.4W; ESP32_C6_LIBRARY_4_ESP32_C6_LIBRARY_4_ESP32_C6_LIBRARY_4_ES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
EPD_C1, EPD_C2, EPD_C6, EPD_C7, EPD_C8, EPD_C9, EPD_C11, EPD_C12: 1uF/50V; NORDIC_NRF_3_RESC0402_L
EPD_C5: 0.1uF/50V; NORDIC_NRF_3_RESC0201_L
EPD_C10: 1uF/50; NORDIC_NRF_3_RESC0402_L
IC2: DRV2605YZFR; DRV2605YZFR_BGA9C50P3X3_144X144X62
J1: 503480-2400; 503480-2400_5034802400
J4: KH-TYPE-C-16P; KH-TYPE-C-16P_KINGHELM_KH-TYPE-C-16P
L5: 68uH; ESP32_C6_LIBRARY_2_IND_4828-WE-TPC_WRE
Q3: SI1308EDL-T1-GE3; ESP32_C6_LIBRARY_6_SOT65P210X110-3N
R1_EP_DR: 0.47; ERA-1AEB3401C_0201
R1_USB, R2_USB: 5K1; ERA-1AEB3401C_0201
R2_EP_DR, R5, R8: 10K; ERA-1AEB3401C_0201
R7: 10k; ERA-1AEB3401C_0201
R_PWR_EPD: 10K; ERA-1AEB3401C_0201
R_TYPE_SEL: 2.2; ERA-1AEB3401C_0201
SJ1: ESP32_C6_LIBRARY_7_JUMPER_SJ
SW_DN: 2025-10-22_07-23-44_LIBRARY_EVP-AKE31ASW_EVP-AKE3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; 2025-10-22_07-23-44_LIBRARY_SW_EVP-AKE31A_PAN
SW_ENT: 2025-10-22_07-23-44_LIBRARY_EVP-AKE31ASW_EVP-AKE3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; 2025-10-22_07-23-44_LIBRARY_SW_EVP-AKE31A_PAN
SW_UP: 2025-10-22_07-23-44_LIBRARY_EVP-AKE31ASW_EVP-AKE3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; 2025-10-22_07-23-44_LIBRARY_SW_EVP-AKE31A_PAN
TP_BAT_GND: HECTOR_WATCH_1_TPTP20R; HECTOR_WATCH_1_TP20R
TP_ON: HECTOR_WATCH_1_TPTP20R; HECTOR_WATCH_1_TP20R
TP_OP: HECTOR_WATCH_1_TPTP20R; HECTOR_WATCH_1_TP20R
TP_VBAT: HECTOR_WATCH_1_TPTP20R; HECTOR_WATCH_1_TP20R
U3: MAX17048G+T10; ESP32_C6_LIBRARY_SON50P200X200X80-9N

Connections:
3V3: C34.2, DMG2305UX-7.2 (S), IC2.C2 (VDD), R5.2, R7.2, R8.2, R_PWR_EPD.2; also elsewhere on the board
ALERT: U3.5 (!ALERT); also elsewhere on the board
D+: D3.4 (I/O2_2); also elsewhere on the board
D-: D3.6 (I/O1_2); also elsewhere on the board
DN: D3.1 (I/O1_1), J4.A7 (DN1), J4.B7 (DN2)
DP: D3.3 (I/O2_1), J4.A6 (DP1), J4.B6 (DP2)
EPD_3V3: C1-EP-DR.1, DMG2305UX-7.3 (D), EPD_C5.1, J1.15, J1.16, L5.2
EPD_BUSY: J1.9; also elsewhere on the board
EPD_CS: J1.12; also elsewhere on the board
EPD_DC: J1.11; also elsewhere on the board
EPD_RST: J1.10; also elsewhere on the board
GDR: J1.2, Q3.1 (G), R2_EP_DR.2
GND: C1-EP-DR.2, C27.1, C29.1, C30.1, C31.1, C32.1, C34.1, C42.2, C43.2, D3.2 (GND), D4.1 (K), EPD_C1.1, EPD_C2.1, EPD_C5.2, EPD_C6.1, EPD_C7.1, EPD_C8.1, EPD_C9.1, EPD_C10.1, EPD_C11.1, EPD_C12.1, IC2.B1 (IN/TRIG), IC2.B3 (GND), J1.8, J1.17, J1.MP1, J1.MP2, J4.A1_B12 (GND), J4.A12_B1 (GND), J4.SH1 (SHIELD), J4.SH2 (SHIELD), J4.SH3 (SHIELD), J4.SH4 (SHIELD), R1_USB.1, R2_EP_DR.1, R2_USB.2, R_TYPE_SEL.1, SJ1.1, SW_DN.1, SW_ENT.1, SW_UP.1, TP_BAT_GND.TP, U3.1 (CTG), U3.4 (GND), U3.6 (QSTRT), U3.9 (EP); also elsewhere on the board
HAPTIC_EN: IC2.A1 (EN); also elsewhere on the board
MOSI: J1.14; also elsewhere on the board
unnamed: C32.2, IC2.A2 (REG)
unnamed: C2-EP-DR.2, D5.2 (A), L5.1, Q3.3 (D)
unnamed: C2-EP-DR.1, D2.1 (K), D4.2 (A)
unnamed: J4.B5 (CC2), R2_USB.1
unnamed: J4.A5 (CC1), R1_USB.2
unnamed: EPD_C2.2, J1.4
unnamed: EPD_C1.2, J1.5
unnamed: R1_EP_DR.1, R_TYPE_SEL.2, SJ1.2
unnamed: EPD_C6.2, J1.18
unnamed: EPD_C7.2, J1.19
unnamed: EPD_C8.2, J1.20
unnamed: EPD_C10.2, J1.22
unnamed: EPD_C12.2, J1.24
OUT+: IC2.A3 (OUT+), TP_OP.TP
OUT-: IC2.C3 (OUT-), TP_ON.TP
P0.13: C30.2, R5.1, SW_UP.2; also elsewhere on the board
P0.14: C31.2, R8.1, SW_ENT.2; also elsewhere on the board
P1.01: DMG2305UX-7.1 (G), R_PWR_EPD.1; also elsewhere on the board
P1.02: C29.2, R7.1, SW_DN.2; also elsewhere on the board
PREVGH: D5.1 (K), EPD_C9.2, J1.21
PREVGL: D2.2 (A), EPD_C11.2, J1.23
RESE: J1.3, Q3.2 (S), R1_EP_DR.2
SCK: J1.13; also elsewhere on the board
SCL: IC2.C1 (SCL), U3.7 (SCL); also elsewhere on the board
SDA: IC2.B2 (SDA), U3.8 (SDA); also elsewhere on the board
VBAT: C27.2, TP_VBAT.TP, U3.2 (CELL), U3.3 (VDD); also elsewhere on the board
VBUS: C42.1, C43.1, D3.5 (VBUS), J4.A4_B9 (VBUS), J4.A9_B4 (VBUS); also elsewhere on the board

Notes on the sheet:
E-Paper Drive Circuit
E-Paper Display Connector
Fuel Gauge
Haptic Driver
Buttons
USB C Connector & ESD Protection

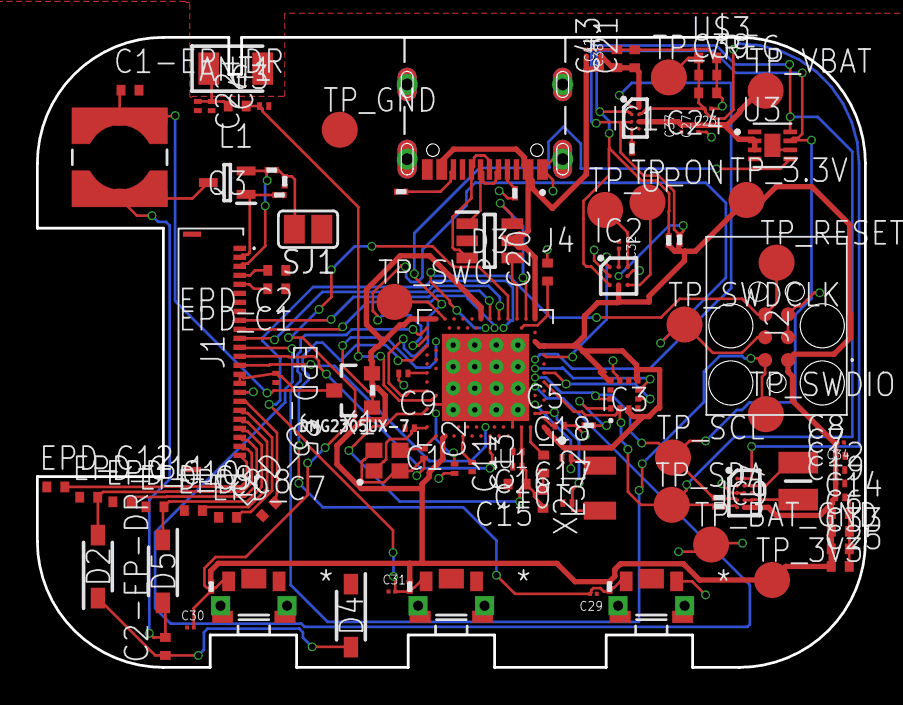
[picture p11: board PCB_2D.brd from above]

Board: 2 copper layers, 46.0 x 35.0 mm, 106 parts (0 on the bottom side), 70 nets.

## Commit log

2026-04-19 Delete Hardware/inktime.brd
    Sters pentru a il inlocui cu ultima varianta buna
    [inktime.brd]
2026-04-19 Delete Hardware/inktime.sch
    Sters pentru a il inlocui cu varianta buna
    [inktime.sch]
2026-04-19 Ultima varianta a folderului Hardware
    [PCB_2D.brd, schematic1.sch, schematic2.sch]
2026-04-19 Am adaugat folderul Images
    Aici se regasesc poze cu: schematicul, PCB 2D si 3D si celelalte componente 3D bateria si displayul
2026-04-20 Enhance README with hardware details and BOM
    Added detailed hardware functionality description, pin allocation, and a Bill of Materials for the InkTime SmartWatch project.
2026-04-20 Revise diagrams and components in README.md
    Updated the power supply and processing unit diagrams, and modified peripheral components in the README.

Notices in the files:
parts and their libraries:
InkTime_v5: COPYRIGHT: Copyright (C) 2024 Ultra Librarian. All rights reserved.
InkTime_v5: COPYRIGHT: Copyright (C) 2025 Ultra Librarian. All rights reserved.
